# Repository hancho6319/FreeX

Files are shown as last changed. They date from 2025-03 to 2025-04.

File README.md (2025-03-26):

############## Install React-Native ###############

# npx @react-native-community/cli init LEDControlApp

OR

# expo install expo-dev-client
# expo run:android

################# How to Run Your App Now ################
Since you are using Bluetooth, you need to build a development client instead of using Expo Go. Here’s what to do:

1️⃣ Install Expo Dev Client
Run this in your project:

# npm install -g eas-cli

# eas build:configure

2️⃣ Build a Development Client
------------- For Android, run -----------------

# eas build --profile development --platform android

--------------- For iOS (if on macOS)-------------

# eas build --profile development --platform ios

Wait for it to build, then download and install the .apk (Android) or .ipa (iOS) on your device.

3️⃣ Run Your App on a Real Device
Now, use this command to run your app:

------------->  Connect your phone to your PC using a USB cable. <-------------

Open a terminal and run:

# adb devices
# adb pair <DEVICE_IP>:<PAIRING_PORT> <PAIRING_CODE>
# adb connect <DEVICE_IP>:5555

------------------------> All set, then <--------------------------

# npx react-native run-android

# npx expo start --dev-client

############# Alternative: Use an Emulator ############
If you prefer not to build a .apk, you can run the app using Android Studio’s emulator:

# npx expo run:android
Let me know if you need help with this! 🚀

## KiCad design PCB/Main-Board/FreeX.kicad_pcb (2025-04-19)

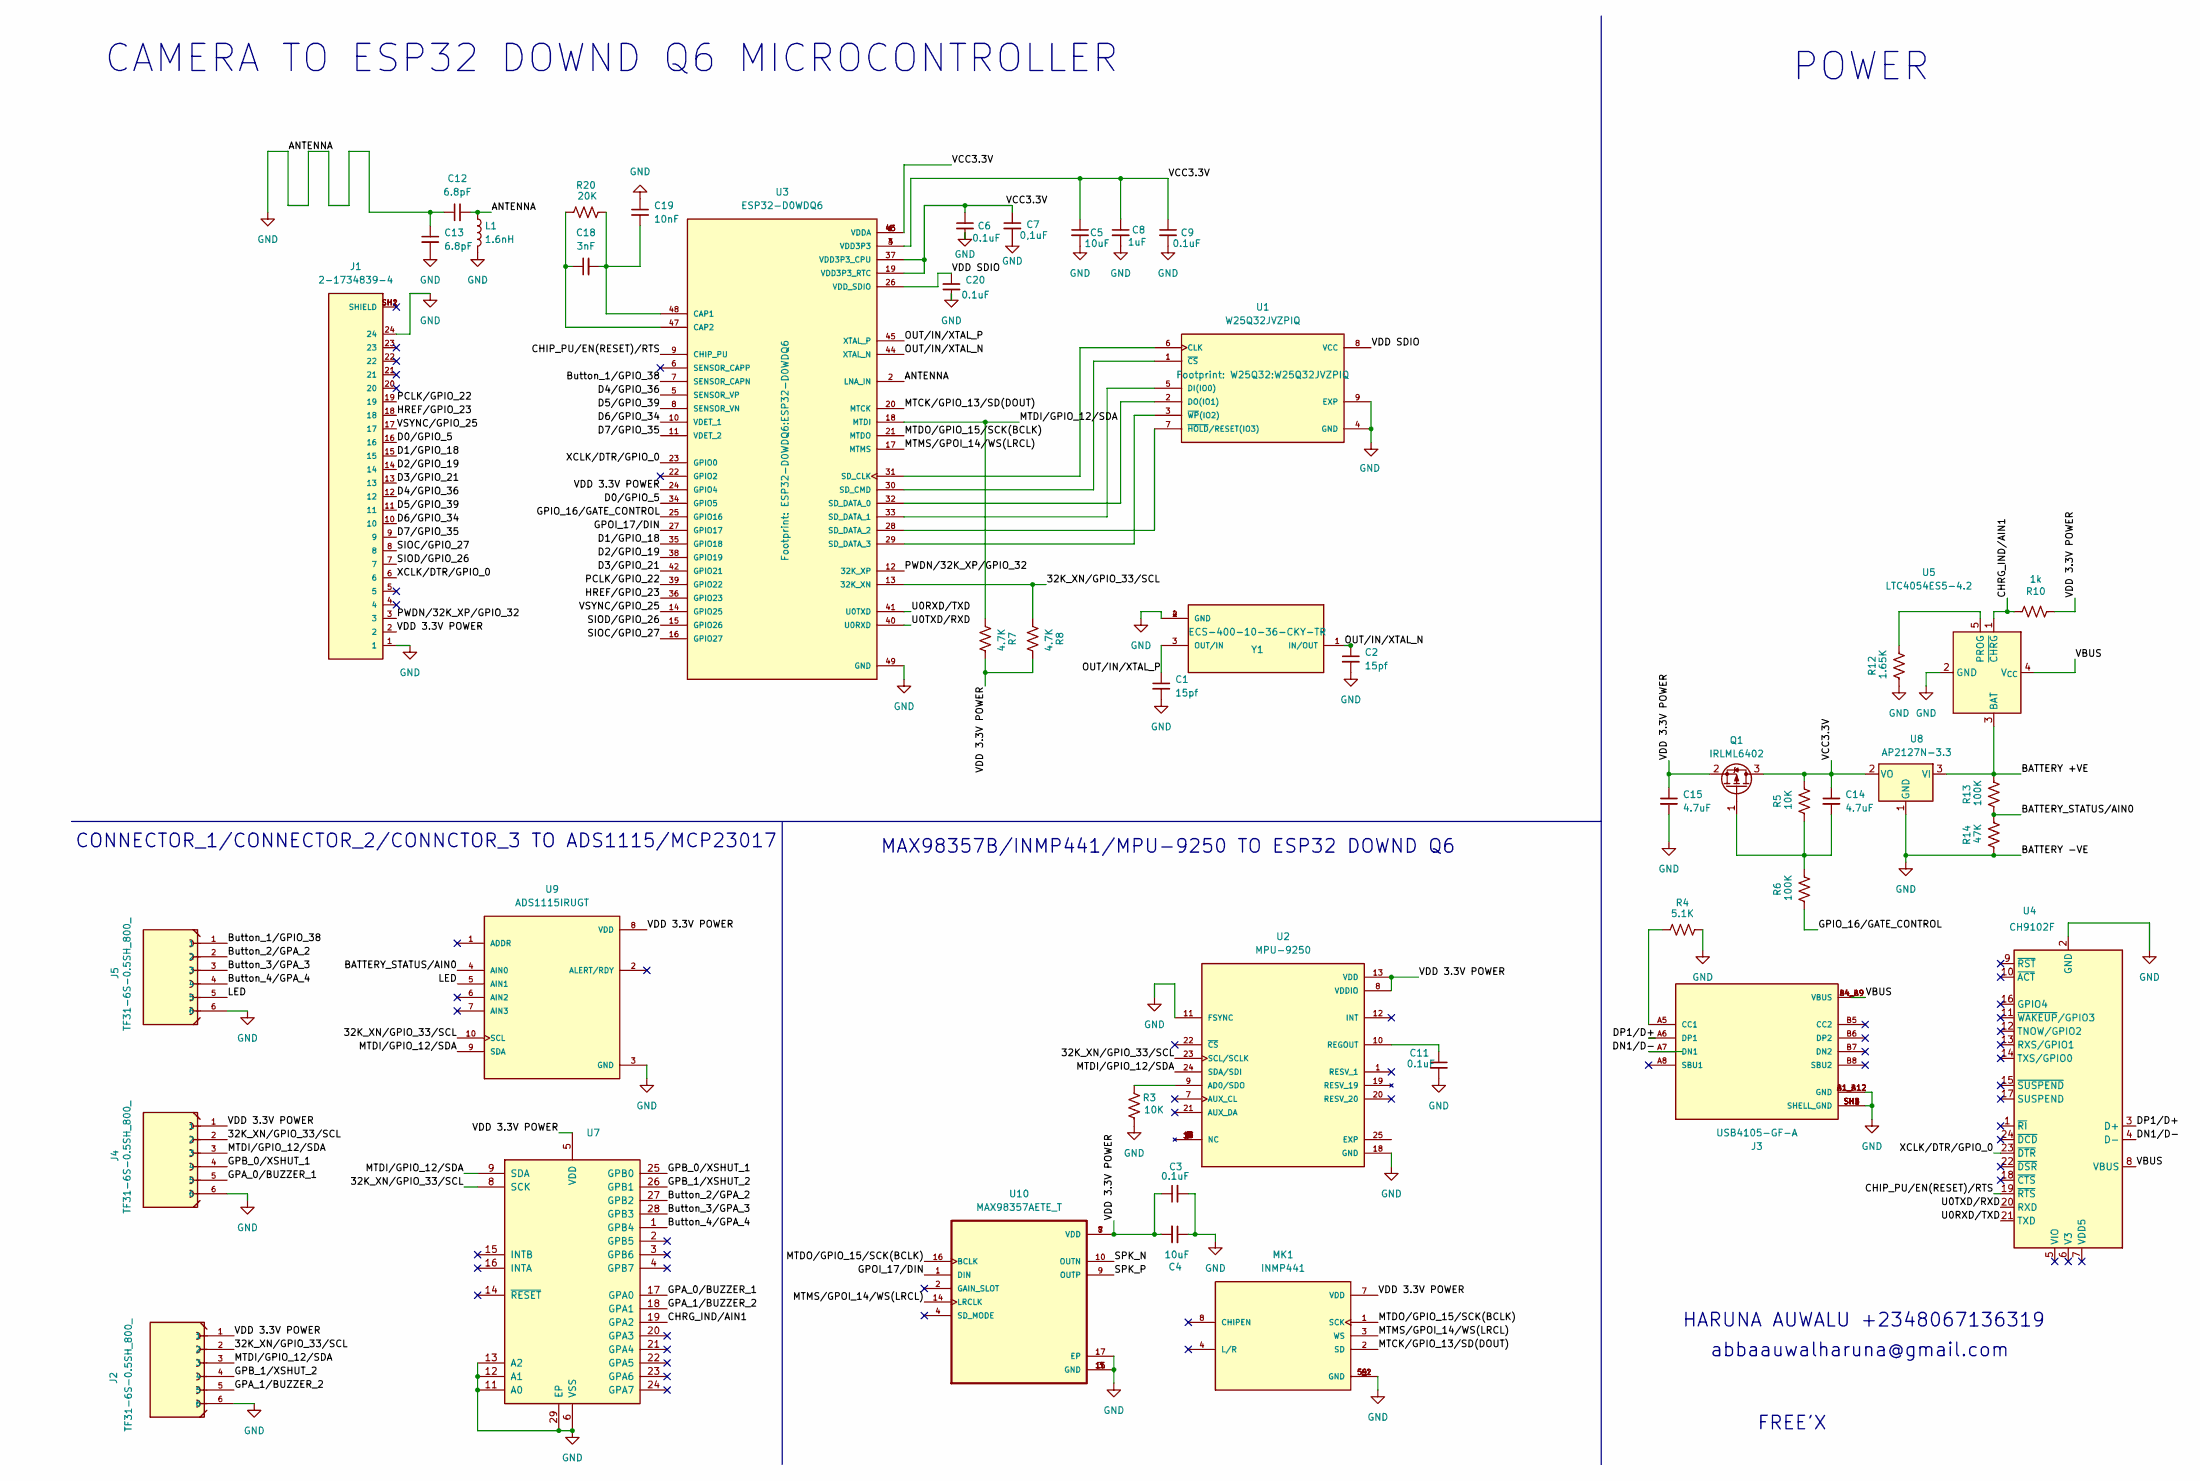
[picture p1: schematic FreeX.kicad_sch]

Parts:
C1, C2: 15pf; C_0201_0603Metric
C3, C6, C9, C11, C20: 0.1uF; C_0201_0603Metric
C4, C5: 10uF; C_0201_0603Metric
C7: 0,1uF; C_0201_0603Metric
C8: 1uF; C_0201_0603Metric
C12, C13: 6.8pF; C_0201_0603Metric
C14, C15: 4.7uF; C_0201_0603Metric
C18: 3nF; C_0201_0603Metric
C19: 10nF; C_0201_0603Metric
J1: 2-1734839-4; 2-1734839-4 pin-24; PARTREV 05-06
J2, J4, J5: TF31-6S-0.5SH_800_; TF31-6S-0.5SH_800-6-pins
J3: USB4105-GF-A; USB4105-GF-A TYPE C; PARTREV B4
L1: 1.6nH; L_0201_0603Metric
MK1: INMP441; MIC_INMP441; PARTREV 1.1
Q1: IRLML6402; SOT-23
R3, R5: 10K; R_0201_0603Metric
R4: 5.1K; R_0201_0603Metric
R6, R13: 100K; R_0201_0603Metric
R7, R8: 4.7K; R_0201_0603Metric
R10: 1k; R_0201_0603Metric
R12: 1.65K; R_0201_0603Metric
R14: 47K; R_0201_0603Metric
R20: 20K; R_0201_0603Metric
U1: W25Q32JVZPIQ
U2: MPU-9250; MPU-9250 SENSOR; PARTREV 1.1
U3: ESP32-D0WDQ6; PARTREV v3.9
U4: CH9102F; QFN-24-1EP_4x4mm_P0.5mm_EP2.6x2.6mm
U5: LTC4054ES5-4.2; TSOT-23-5
U7: MCP23017_ML; QFN-28-1EP_6x6mm_P0.65mm_EP4.25x4.25mm
U8: AP2127N-3.3; SOT-23
U9: ADS1115IRUGT; PARTREV B
U10: MAX98357AETE_T
Y1: ECS-400-10-36-CKY-TR; PARTREV 2017

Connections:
/32K_XN/GPIO_33/SCL: J2.2, J4.2, R8.1, U2.23 (SCL/SCLK), U3.13 (32K_XN), U7.8 (SCK), U9.10 (SCL)
/BATTERY +VE: R13.2, U5.3 (BAT), U8.3 (VI)
/BATTERY_STATUS/AIN0: R13.1, R14.2, U9.4 (AIN0)
/Button_1/GPIO_38: J5.1, U3.7 (SENSOR_CAPN)
/Button_2/GPA_2: J5.2, U7.27 (GPB2)
/Button_3/GPA_3: J5.3, U7.28 (GPB3)
/Button_4/GPA_4: J5.4, U7.1 (GPB4)
/CHIP_PU/EN(RESET)/RTS: U3.9 (CHIP_PU), U4.19 (~RTS)
/CHRG_IND/AIN1: R10.1, U5.1 (~CHRG), U7.19 (GPA2)
/D0/GPIO_5: J1.16, U3.34 (GPIO5)
/D1/GPIO_18: J1.15, U3.35 (GPIO18)
/D2/GPIO_19: J1.14, U3.38 (GPIO19)
/D3/GPIO_21: J1.13, U3.42 (GPIO21)
/D4/GPIO_36: J1.12, U3.5 (SENSOR_VP)
/D5/GPIO_39: J1.11, U3.8 (SENSOR_VN)
/D6/GPIO_34: J1.10, U3.10 (VDET_1)
/D7/GPIO_35: J1.9, U3.11 (VDET_2)
/DN1/D-: J3.A7 (DN1), U4.4 (D-)
/DP1/D+: J3.A6 (DP1), U4.3 (D+)
/GPA_0/BUZZER_1: J4.5, U7.17 (GPA0)
/GPA_1/BUZZER_2: J2.5, U7.18 (GPA1)
/GPB_0/XSHUT_1: J4.4, U7.25 (GPB0)
/GPB_1/XSHUT_2: J2.4, U7.26 (GPB1)
/GPIO_16/GATE_CONTROL: R6.1, U3.25 (GPIO16)
/GPOI_17/DIN: U3.27 (GPIO17), U10.1 (DIN)
/HREF/GPIO_23: J1.18, U3.36 (GPIO23)
/LED: J5.5, U9.5 (AIN1)
/MTCK/GPIO_13/SD(DOUT): MK1.2 (SD), U3.20 (MTCK)
/MTDI/GPIO_12/SDA: J2.3, J4.3, R7.1, U2.24 (SDA/SDI), U3.18 (MTDI), U7.9 (SDA), U9.9 (SDA)
/MTDO/GPIO_15/SCK(BCLK): MK1.1 (SCK), U3.21 (MTDO), U10.16 (BCLK)
/MTMS/GPOI_14/WS(LRCL): MK1.3 (WS), U3.17 (MTMS), U10.14 (LRCLK)
/OUT/IN/XTAL_N: C2.1, U3.44 (XTAL_N), Y1.1 (IN/OUT)
/OUT/IN/XTAL_P: C1.1, U3.45 (XTAL_P), Y1.3 (OUT/IN)
/PCLK/GPIO_22: J1.19, U3.39 (GPIO22)
/PWDN/32K_XP/GPIO_32: J1.3, U3.12 (32K_XP)
/SIOC/GPIO_27: J1.8, U3.16 (GPIO27)
/SIOD/GPIO_26: J1.7, U3.15 (GPIO26)
/SPK_N: U10.10 (OUTN)
/SPK_P: U10.9 (OUTP)
/U0RXD/TXD: U3.41 (U0TXD), U4.21 (TXD)
/U0TXD/RXD: U3.40 (U0RXD), U4.20 (RXD)
/VBUS: J3.A4_B9 (VBUS), J3.B4_A9 (VBUS), U4.8 (VBUS), U5.4 (V_{CC})
/VCC3.3V: C5.1, C6.1, C7.1, C8.1, C9.1, C14.1, Q1.3 (D), R5.2, U3.1 (VDDA), U3.3 (VDD3P3), U3.4 (VDD3P3), U3.19 (VDD3P3_RTC), U3.37 (VDD3P3_CPU), U3.43 (VDDA), U3.46 (VDDA), U8.2 (VO)
/VDD 3.3V POWER: C3.1, C4.2, C15.1, J1.2, J2.1, J4.1, MK1.7 (VDD), Q1.2 (S), R7.2, R8.2, R10.2, U2.8 (VDDIO), U2.13 (VDD), U3.24 (GPIO4), U7.5 (VDD), U9.8 (VDD), U10.7 (VDD), U10.8 (VDD)
/VDD SDIO: C20.1, U1.8 (VCC), U3.26 (VDD_SDIO)
/VSYNC/GPIO_25: J1.17, U3.14 (GPIO25)
/XCLK/DTR/GPIO_0: J1.6, U3.23 (GPIO0), U4.23 (~DTR)
GND: C1.2, C2.2, C3.2, C4.1, C5.2, C6.2, C7.2, C8.2, C9.2, C11.2, C12.1, C12.2, C13.1, C13.2, C15.2, C19.1, C20.2, J1.1, J1.24, J2.6, J3.A1_B12 (GND), J3.B1_A12 (GND), J3.SH1 (SHELL_GND), J3.SH2 (SHELL_GND), J3.SH3 (SHELL_GND), J3.SH4 (SHELL_GND), J4.6, J5.6, L1.1, L1.2, MK1.5_1 (GND), MK1.5_2 (GND), MK1.6 (GND), MK1.9 (GND), R3.2, R4.1, R12.1, R14.1, U1.4 (GND), U1.9 (EXP), U2.11 (FSYNC), U2.18 (GND), U3.2 (LNA_IN), U3.49 (GND), U4.2 (GND), U4.25 (GND), U5.2 (GND), U7.6 (VSS), U7.11 (A0), U7.12 (A1), U7.13 (A2), U7.29 (EP), U8.1 (GND), U9.3 (GND), U10.3 (GND), U10.11 (GND), U10.15 (GND), U10.17 (EP), Y1.2 (GND), Y1.4 (GND)
unnamed: J3.A5 (CC1), R4.2
unnamed: C14.2, Q1.1 (G), R5.1, R6.2
unnamed: U1.6 (CLK), U3.31 (SD_CLK)
unnamed: U1.5 (DI(IO0)), U3.33 (SD_DATA_1)
unnamed: U1.2 (DO(IO1)), U3.32 (SD_DATA_0)
unnamed: U1.1 (~CS), U3.30 (SD_CMD)
unnamed: U1.7 (~HOLD/RESET(IO3)), U3.28 (SD_DATA_2)
unnamed: U1.3 (~WP(IO2)), U3.29 (SD_DATA_3)
unnamed: R3.1, U2.9 (AD0/SDO)
unnamed: C11.1, U2.10 (REGOUT)
unnamed: C18.2, C19.2, R20.2, U3.48 (CAP1)
unnamed: C18.1, R20.1, U3.47 (CAP2)
unnamed: R12.2, U5.5 (PROG)

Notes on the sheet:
HARUNA AUWALU +2348067136319
CONNECTOR_1/CONNECTOR_2/CONNCTOR_3 TO ADS1115/MCP23017
MAX98357B/INMP441/MPU-9250 TO ESP32 DOWND Q6
FREE'X
CAMERA TO ESP32 DOWND Q6 MICROCONTROLLER
abbaauwalharuna@gmail.com
POWER

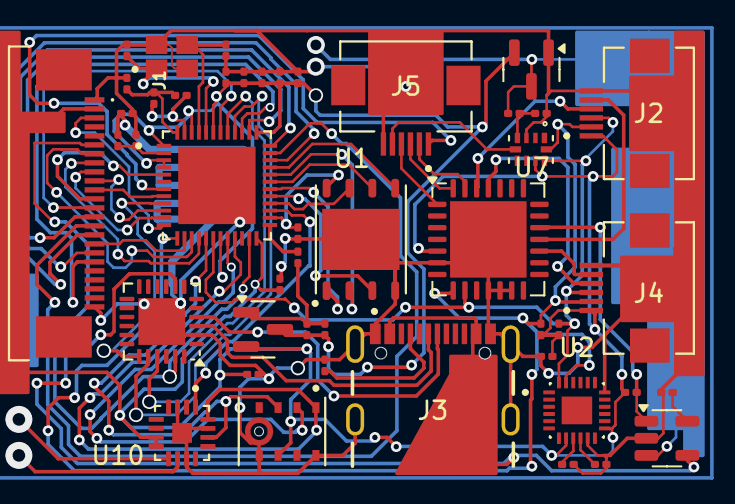
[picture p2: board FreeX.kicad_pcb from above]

Board: 2 copper layers, 46 parts (0 on the bottom side), 59 nets.

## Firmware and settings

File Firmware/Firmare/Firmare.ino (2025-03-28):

#include <BLEDevice.h>
#include <BLEServer.h>
#include <BLEUtils.h>
#include <BLE2902.h> 

#define LED_PIN 4
#define SERVICE_UUID        "4fafc201-1fb5-459e-8fcc-c5c9c331914b"
#define CHARACTERISTIC_UUID "beb5483e-36e1-4688-b7f5-ea07361b26a8"

BLEServer* pServer = NULL;
BLECharacteristic* pCharacteristic = NULL;
bool deviceConnected = false;
bool oldDeviceConnected = false;

class MyServerCallbacks: public BLEServerCallbacks {
    void onConnect(BLEServer* pServer) {
      deviceConnected = true;
      Serial.println("Device connected");
    };

    void onDisconnect(BLEServer* pServer) {
      deviceConnected = false;
      Serial.println("Device disconnected");
    }
};

class MyCallbacks: public BLECharacteristicCallbacks {
    void onWrite(BLECharacteristic *pCharacteristic) {
      std::string value = pCharacteristic->getValue().c_str();
      
      if (value.length() > 0) {
        Serial.print("Received Raw Value: ");
        Serial.print((int)value[0]);
        Serial.println();
        
        if ((int)value[0] == 212) {
          digitalWrite(LED_PIN, HIGH);
          Serial.println("LED ON command received");
        } else if ((int)value[0] == 216) {
          digitalWrite(LED_PIN, LOW);
          Serial.println("LED OFF command received");
        } else {
          Serial.println("Unknown command received");
        }
        Serial.println();
      }
    }
};

void setup() {
  Serial.begin(115200);
  pinMode(LED_PIN, OUTPUT);
  digitalWrite(LED_PIN, LOW);

  // Create the BLE Device
  BLEDevice::init("FreeX");

  // Create the BLE Server
  pServer = BLEDevice::createServer();
  pServer->setCallbacks(new MyServerCallbacks());

  // Create the BLE Service
  BLEService *pService = pServer->createService(SERVICE_UUID);

  // Create a BLE Characteristic
  pCharacteristic = pService->createCharacteristic(
                      CHARACTERISTIC_UUID,
                      BLECharacteristic::PROPERTY_READ   |
                      BLECharacteristic::PROPERTY_WRITE  |
                      BLECharacteristic::PROPERTY_NOTIFY |
                      BLECharacteristic::PROPERTY_INDICATE
                    );

  pCharacteristic->setCallbacks(new MyCallbacks());
  
  // Create a BLE Descriptor
  pCharacteristic->addDescriptor(new BLE2902());

  // Start the service
  pService->start();

  // Start advertising
  BLEAdvertising *pAdvertising = BLEDevice::getAdvertising();
  pAdvertising->addServiceUUID(SERVICE_UUID);
  pAdvertising->setScanResponse(false);
  pAdvertising->setMinPreferred(0x0);
  BLEDevice::startAdvertising();
  Serial.println("Waiting for a client connection to notify...");
}

void loop() {
  if (!deviceConnected && oldDeviceConnected) {
    delay(500);
    pServer->startAdvertising();
    Serial.println("Start advertising");
    oldDeviceConnected = deviceConnected;
  }
  
  if (deviceConnected && !oldDeviceConnected) {
    oldDeviceConnected = deviceConnected;
  }
  
  delay(1000);
}

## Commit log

2025-03-06 6rd march 2025
    [FreeX.kicad_pcb, FreeX.kicad_sch]
2025-03-09 9th, March 2025
    [FreeX.kicad_pcb, FreeX.kicad_sch]
2025-03-14 14th, march. 2025
    [FreeX.kicad_pcb, FreeX.kicad_sch]
2025-03-15 15th, march. 2025
    [FreeX.kicad_sch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]
2025-03-19 19th March 2025
    [FreeX.kicad_pcb, FreeX.kicad_sch]
2025-04-19 4th, April. 2025
    [FreeX.kicad_pcb, FreeX.kicad_sch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]
